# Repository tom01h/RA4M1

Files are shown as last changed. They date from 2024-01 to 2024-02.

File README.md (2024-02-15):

# Arduino UNO R4 もどき

## 買ったもの

- [これ(WeActStudio RA4M1)](https://ja.aliexpress.com/item/1005006103872563.html)の3.3V版
- 基板作った
    - LCDとI2C(J8)とUART(J7)とRTC電池(BT1)とSPIフラッシュ(U1)は使えた
    - 他にHX711とつなぐコネクタがある
    - Analog入力も後で試す

## Arduino化

- [Arduino公式のダウンロードページ](https://github.com/arduino/ArduinoCore-renesas/tree/main/bootloaders/UNO_R4)からファームウェア(dfu_minima.hex)をダウンロード
- [Renesas公式のダウンロードページ](https://www.renesas.com/us/en/software-tool/renesas-flash-programmer-programming-gui)からFlash Programmerをダウンロードしてインストール
    - ユーサー登録が必要だった
- [ここ](https://community.element14.com/products/arduino/b/blog/posts/arduino-uno-r4-minima-troubleshooting-unknown-usb-device)のReflash the Bootloader以降に従ってファームウェアを書き込む
    - USBでつなぐ
    - MDボタンを押しながらリセットを押してからはなす（そのあとでMDボタンをはなす）×2回？
        - UARTが生えてくるので番号を覚えておく
    - Flash Programmer起動
        - Connect Settings tabでUARTを選ぶ
        - dfu_minima.hexを読み込む
        - 新しいプロジェクトを作ってセーブ
        - Startを押す (書き込む)
- Example Blinkで確認
    - LED_BUILTINはこのボードにはついていない
    - LED_BUILTINをLED_TXに変更すると動いた（3か所）
- 他にも[サンプルがある](https://github.com/arduino/ArduinoCore-renesas/tree/main/libraries)

## OLED 表示
- SSD1306を使っている[128x32 OLED LCD](https://ja.aliexpress.com/item/32850288143.html)に表示する
- [ここ](https://101010.fun/iot/arduino-oled-display.html)を参考にした
- u8g2ライブラリをインストールする
- GND-＞GND:VCC-＞VCC:100->SCK:101->SDA につなぐ（J4につなぐ）
- OLED.ino を書き込む

## 温湿気圧・CO2濃度計
BME280とMH-Z19をつないで温度・湿度・気圧と二酸化炭素濃度を表示する  
5V電源がないので外部から持ってくる（GNDに注意！！）
- インストールするライブラリ
    - u8g2
    - SparkFun BME280
    - Mzh19 by Eduard
- ピン配は以下の図を参照
- weather.inoを書き込む

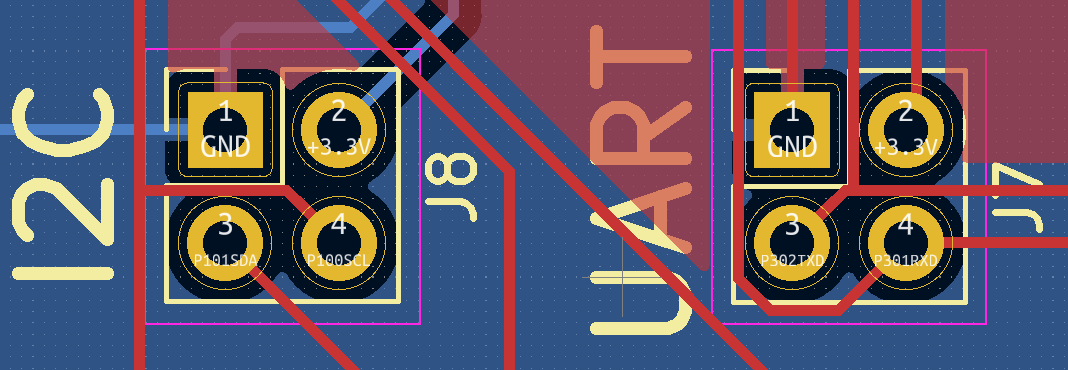
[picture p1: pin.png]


## 時計
RTC電池を使って時計を動かす（純正のR4 Minimaには電池繋げません）  
電池ホルターは[これ](https://ja.aliexpress.com/item/4000528748796.html)
- 電池ホルダーBT1にCR1220を入れる
- RTC_AutomaticExample.inoを書き込む
- [バッテリバックアップを使うとき](https://docs.arduino.cc/tutorials/uno-r4-wifi/vrtc-off/)を参考に改変している
- 内蔵クロックを使うと時計の精度がとっても悪いので[外部のオシレータを使う方法](https://me-yoh.com/arduino-uno-r4-rtc-fix)
    - VBATTを使うと外部のオシレータを発振出来ていません

## SPIフラッシュアクセス

[これ](https://ja.aliexpress.com/item/32326265518.html)
- ライブラリは[Arduino-W25Q64](https://github.com/Tamakichi/Arduino-W25Q64)
- READMEに従って手動でライブラリをインストール
- U1につなぐ
- 繋いでいるのはW25Q32だけど使えるらしい
- Arduino-W25Q64.inoを書き込む

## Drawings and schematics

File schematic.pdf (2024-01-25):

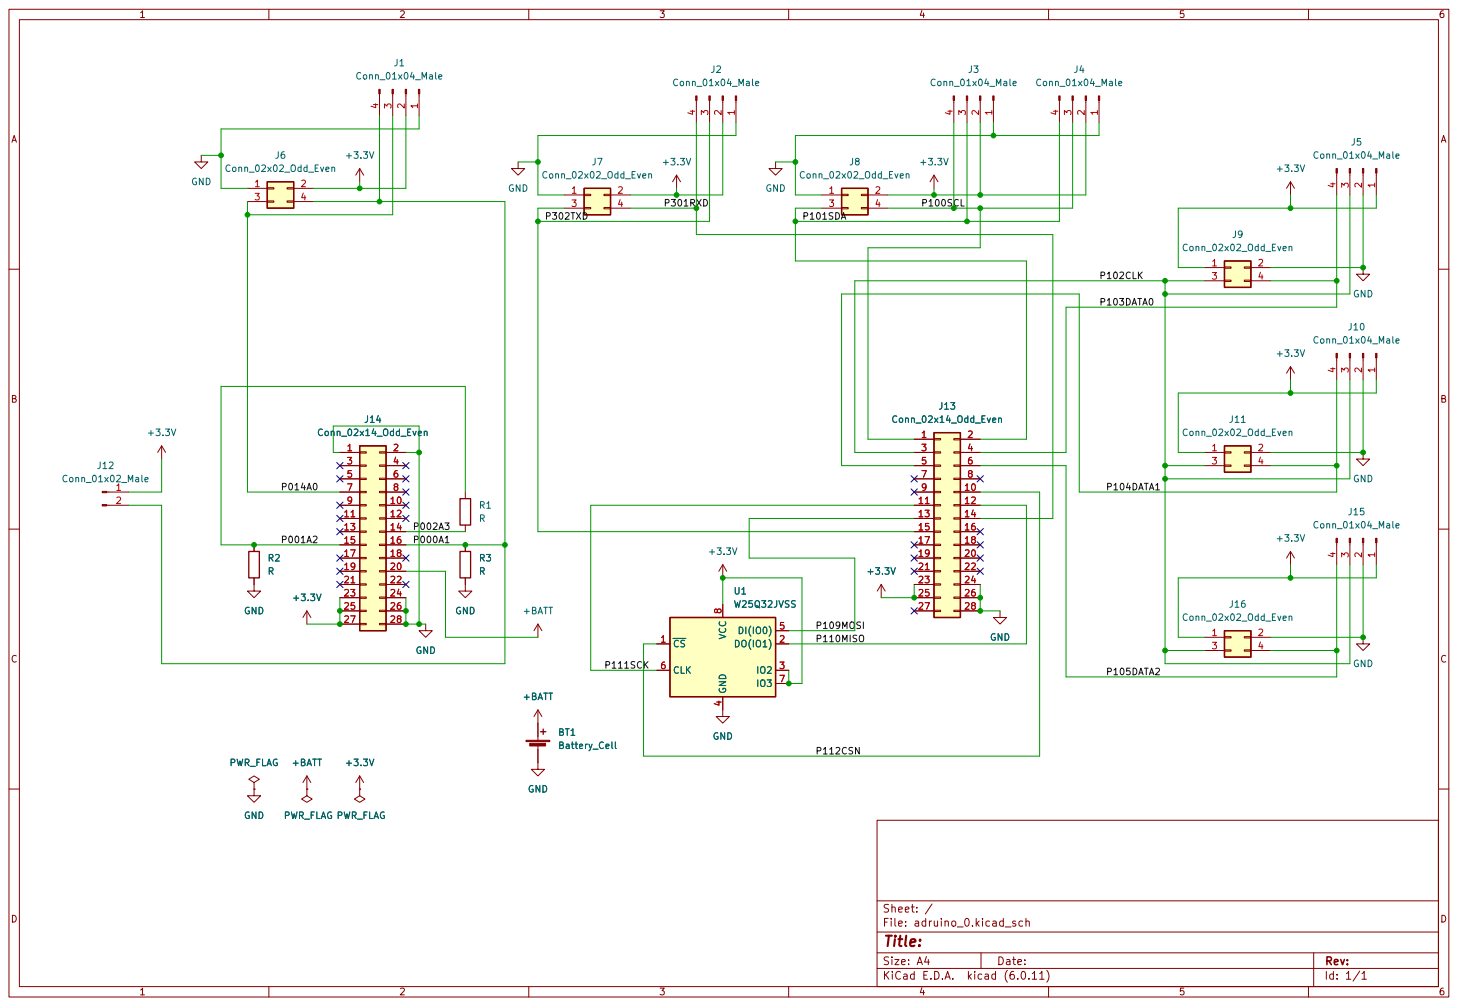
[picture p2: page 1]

Id: 1/1 Title: File: adruino_0.kicad_sch Sheet: /

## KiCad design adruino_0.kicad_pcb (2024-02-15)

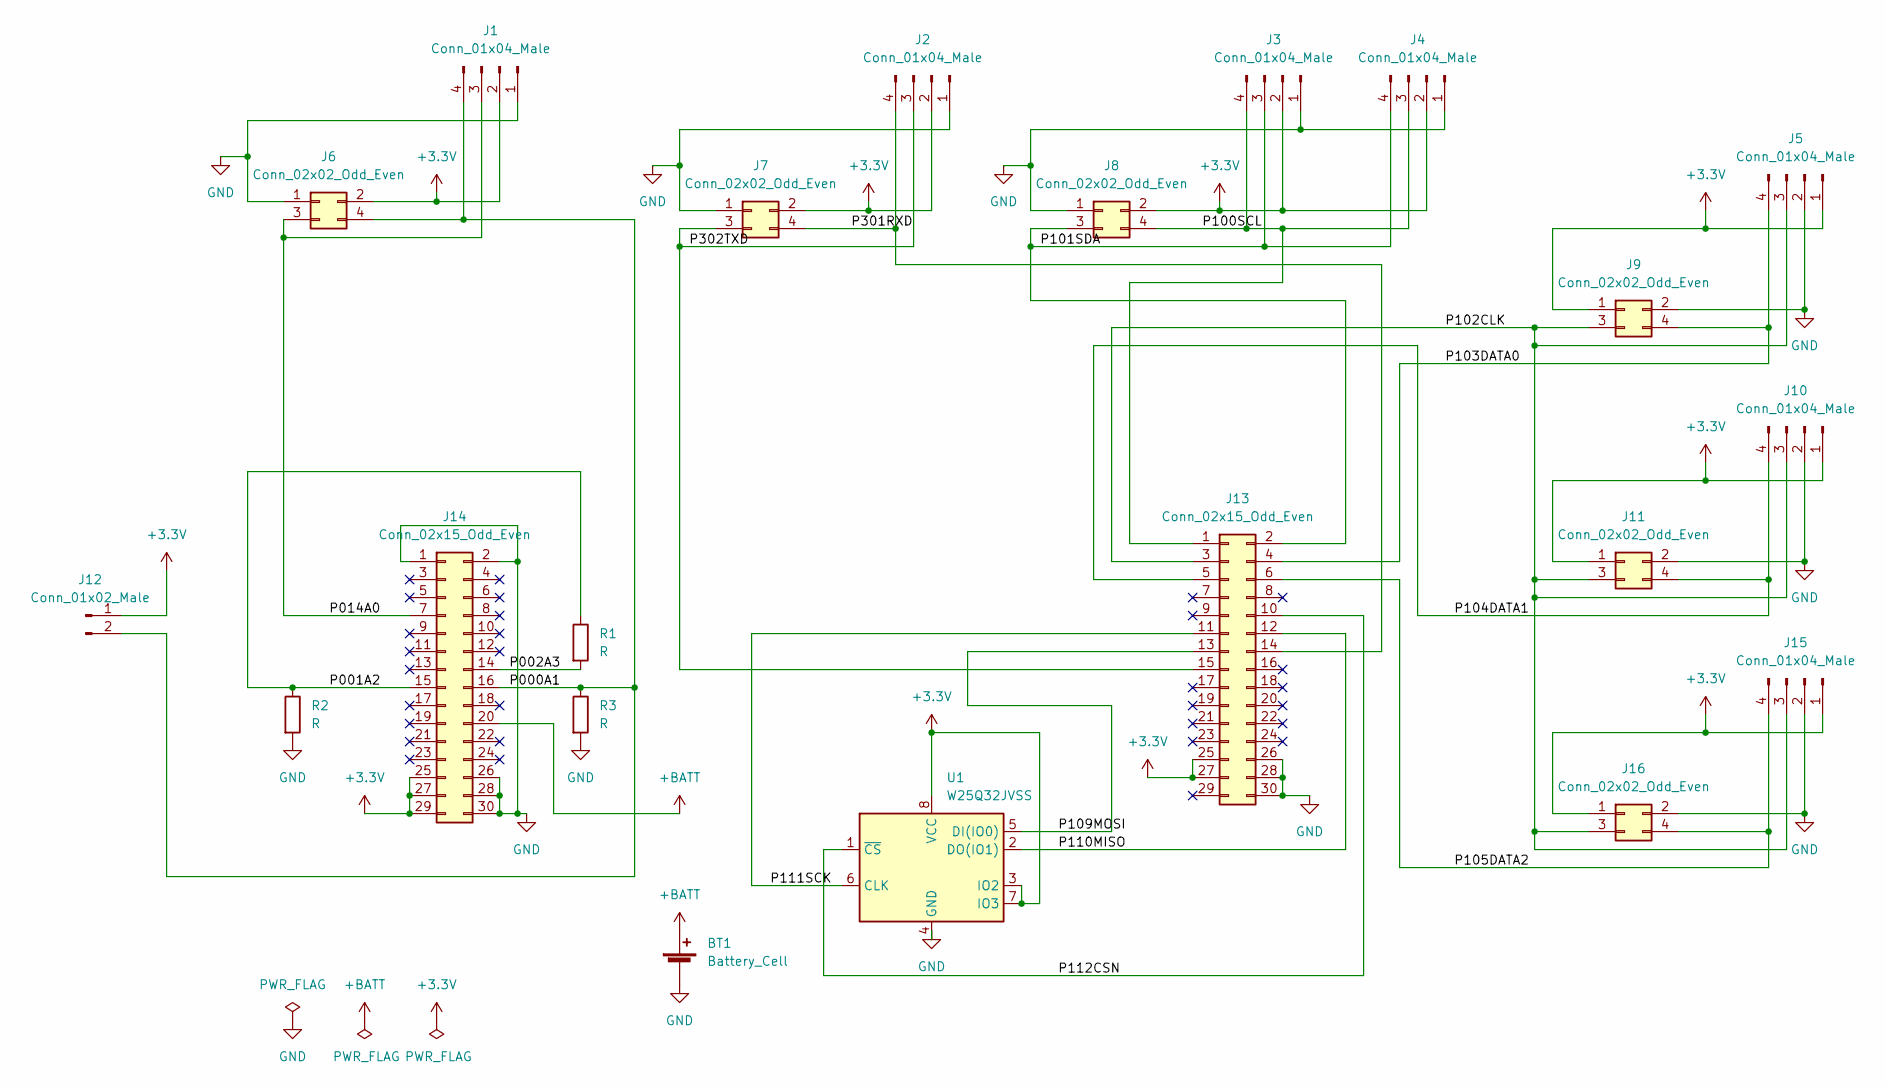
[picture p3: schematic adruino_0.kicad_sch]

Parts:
BT1: Battery_Cell; CH291-1220LF
J1, J2, J3, J5, J10, J15: Conn_01x04_Male; JST_PH_S4B-PH-K_1x04_P2.00mm_Horizontal
J4: Conn_01x04_Male; PinHeader_1x04_P2.54mm_Vertical
J6, J7, J8, J9, J11, J16: Conn_02x02_Odd_Even; PinHeader_2x02_P2.54mm_Vertical
J12: Conn_01x02_Male; PinHeader_1x02_P2.54mm_Vertical
J13, J14: Conn_02x15_Odd_Even; PinHeader_2x15_P2.54mm_Vertical
R1, R2, R3: R; R_1206_3216Metric_Pad1.30x1.75mm_HandSolder
U1: W25Q32JVSS; SOIC-8_5.23x5.23mm_P1.27mm

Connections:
+3.3V: J1.2, J2.2, J3.2, J4.2, J5.1, J6.2, J7.2, J8.2, J9.1, J10.1, J11.1, J12.1, J13.25, J13.27, J14.25, J14.27, J14.29, J15.1, J16.1, U1.3 (IO2), U1.7 (IO3), U1.8 (VCC)
+BATT: BT1.1 (+), J14.20
/P000A1: J1.4, J6.4, J12.2, J14.16, R3.1
/P001A2: J14.15, R1.1, R2.1
/P002A3: J14.14, R1.2
/P014A0: J1.3, J6.3, J14.7
/P100SCL: J3.4, J4.3, J8.4, J13.1
/P101SDA: J3.3, J4.4, J8.3, J13.2
/P102CLK: J5.3, J9.3, J10.3, J11.3, J13.3, J15.3, J16.3
/P103DATA0: J5.4, J9.4, J13.4
/P104DATA1: J10.4, J11.4, J13.5
/P105DATA2: J13.6, J15.4, J16.4
/P109MOSI: J13.13, U1.5 (DI(IO0))
/P110MISO: J13.12, U1.2 (DO(IO1))
/P111SCK: J13.11, U1.6 (CLK)
/P112CSN: J13.10, U1.1 (~CS)
/P301RXD: J2.4, J7.4, J13.14
/P302TXD: J2.3, J7.3, J13.15
GND: BT1.2 (-), J1.1, J2.1, J3.1, J4.1, J5.2, J6.1, J7.1, J8.1, J9.2, J10.2, J11.2, J13.26, J13.28, J13.30, J14.1, J14.2, J14.26, J14.28, J14.30, J15.2, J16.2, R2.2, R3.2, U1.4 (GND)

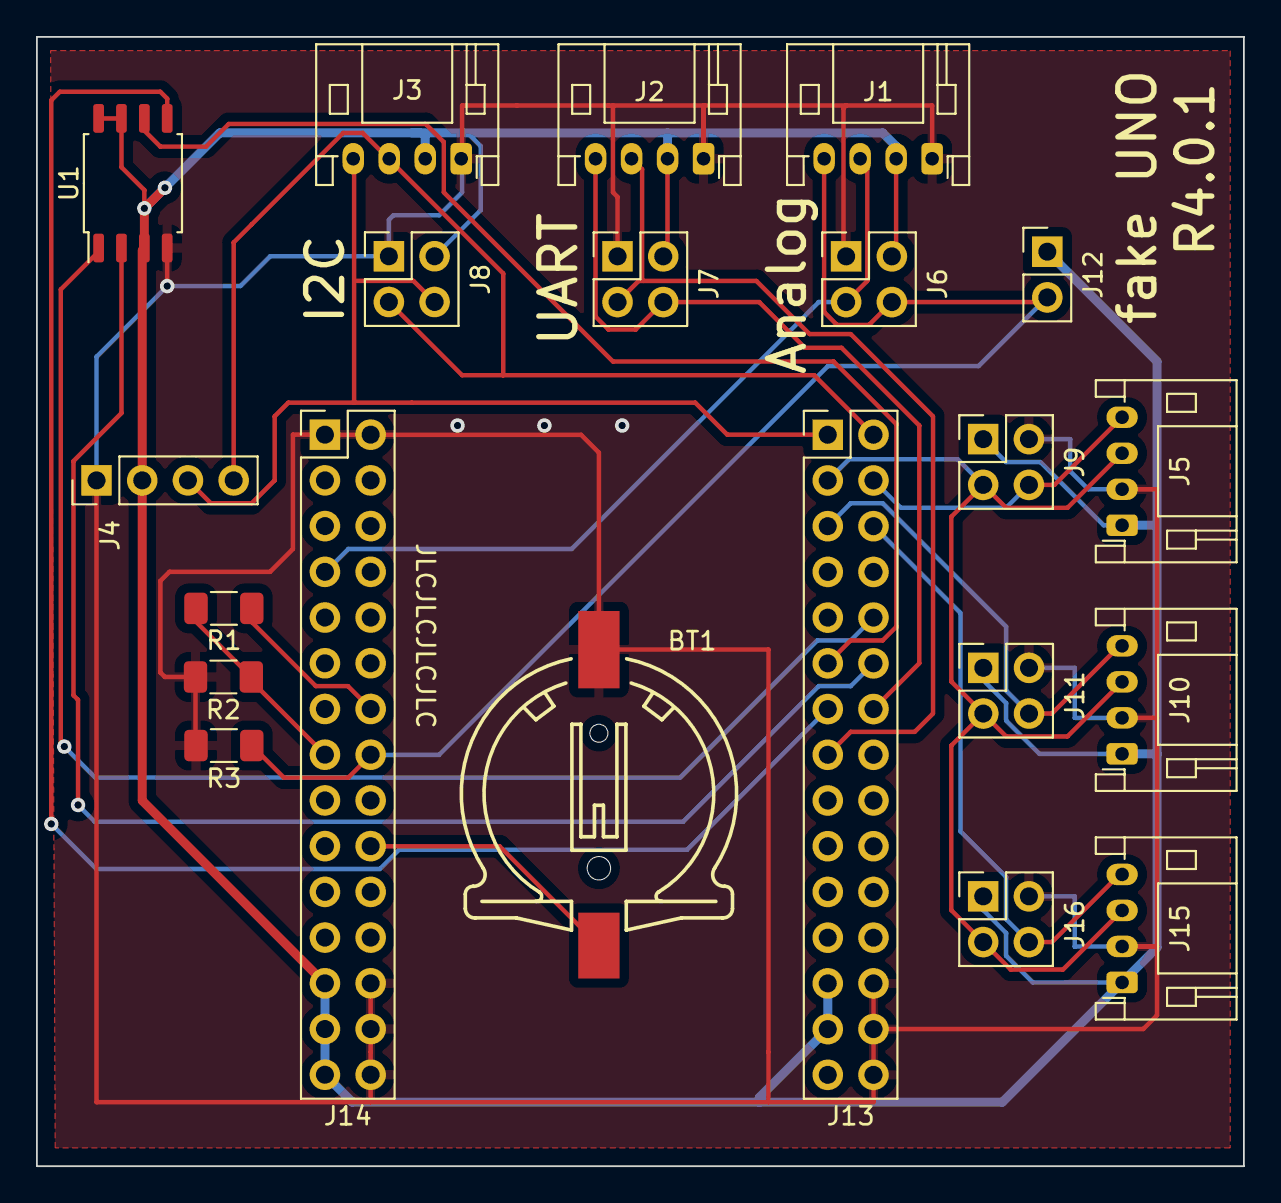
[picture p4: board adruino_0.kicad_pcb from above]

Board: 2 copper layers, 67.1 x 62.7 mm, 21 parts (0 on the bottom side), 19 nets.

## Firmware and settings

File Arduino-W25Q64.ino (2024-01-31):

//
// SPI シリアルフラッシュメモリ W25Q64 操作検証プログラム
// W25Q64のメモリ領域構造
//   総バイト数 8388608
//   メモリ空間 24ビットアドレス指定 0x00000 - 0x7FFFFF 
//   ブロック数 128 (64KB/ブロック)
//   セクタ数 2048  ( 4KB/セクタ)
//   総セクタ数 2048
//
//  修正 2020/05/12, Unique ID取得の修正
//

#include <string.h>
#include <W25Q64.h>

//
// 書込みデータのダンプリスト
// dt(in) : データ格納先頭アドレス
// n(in)  : 表示データ数
//
void dump(byte *dt, uint32_t n) {
  char buf[64];
  uint16_t clm = 0;
  byte data;
  byte sum;
  byte vsum[16];
  byte total =0;
  uint32_t saddr =0;
  uint32_t eaddr =n-1;
  
  Serial.println("----------------------------------------------------------");
  for (uint16_t i=0;i<16;i++) vsum[i]=0;  
  for (uint32_t addr = saddr; addr <= eaddr; addr++) {
    data = dt[addr];
    if (clm == 0) {
      sum =0;
      sprintf(buf,"%05lx: ",addr);
      Serial.print(buf);
    }

    sum+=data;
    vsum[addr % 16]+=data;
    
    sprintf(buf,"%02x ",data);
    Serial.print(buf);
    clm++;
    if (clm == 16) {
      sprintf(buf,"|%02x ",sum);
      Serial.print(buf);      
      Serial.println("");
      clm = 0;
    }    
  }
  Serial.println("----------------------------------------------------------");
  Serial.print("       ");
  for (uint16_t i=0; i<16;i++) {
    total+=vsum[i];
    sprintf(buf,"%02x ",vsum[i]);
    Serial.print(buf);
  }
  sprintf(buf,"|%02x ",total);
  Serial.print(buf);      
  Serial.println("");
  Serial.println("");
}

void setup() {
    byte buf[256];        // 取得データ
    byte wdata[16];       // 書込みデータ
    
    uint16_t n;           // 取得データ数
    
    W25Q64_begin(10);     // フラッシュメモリ利用開始
    Serial.begin(115200);
    while (!Serial) ;

    // JEDEC IDの取得テスト
    W25Q64_readManufacturer(buf);
    Serial.print("JEDEC ID : ");
    for (byte i=0; i< 3; i++) {
      Serial.print(buf[i],HEX);
      Serial.print(" ");
    }
    Serial.println("");
    
    // Unique IDの取得テスト
    memset(buf,0,8);
    W25Q64_readUniqieID(buf);
    Serial.print("Unique ID : ");
    for (byte i=0; i< 8; i++) {
      Serial.print(buf[i],HEX);
      Serial.print(" ");
    }
    Serial.println("");
    
    // データの読み込み(アドレス0から256バイト取得)
    memset(buf,0,256);
    n =  W25Q64_read(0,buf, 256);
    Serial.print("Read Data: n=");
    Serial.println(n,DEC);
    dump(buf,256);

    // 高速データの読み込み(アドレス0から256バイト取得)
    memset(buf,0,256);
    n =  W25Q64_fastread(0,buf, 256);
    Serial.print("Fast Read Data: n=");
    Serial.println(n,DEC);
    dump(buf,256);

    // セクタ単位の削除
    n = W25Q64_eraseSector(0,true);
    Serial.print("Erase Sector(0): n=");
    Serial.println(n,DEC);
    memset(buf,0,256);
    n =  W25Q64_read (0,buf, 256);
    dump(buf,256);
 
    // データ書き込みテスト
    for (byte i=0; i < 16;i++) {
      wdata[i]='A'+i;
    }  
    n =  W25Q64_pageWrite(0, 10, wdata, 16);
    Serial.print("page_write(0,10,d,16): n=");
    Serial.println(n,DEC);
    memset(buf,0,256);
    n =  W25Q64_read (0,buf, 256);
    dump(buf,256);

    // ステータスレジスタ1の取得
    buf[0] = W25Q64_readStatusReg1();
    Serial.print("Status Register-1: ");
    Serial.print(buf[0],BIN);
    Serial.println("");

    // ステータスレジスタ2の取得
    buf[0] = W25Q64_readStatusReg2();
    Serial.print("Status Register-2: ");
    Serial.print(buf[0],BIN);
    Serial.println("");
}

void loop() {

}

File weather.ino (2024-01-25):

#include <Wire.h>
#include "SparkFunBME280.h"

BME280 bme280;

#include <Mhz19.h>

Mhz19 mhz19;

#include <U8g2lib.h>

U8G2_SSD1306_128X32_UNIVISION_F_HW_I2C u8g2(U8G2_R2, /* reset=*/ U8X8_PIN_NONE);

void setup() {
  Serial.begin(115200);

  Wire.begin();
  bme280.setI2CAddress(0x76);
  if(bme280.beginI2C() == false) Serial.println("Sensor connect failed");

  Serial1.begin(9600);
  while(Serial1.available()){
    delay(2);
  }
  mhz19.begin(&Serial1);
  mhz19.setMeasuringRange(Mhz19MeasuringRange::Ppm_5000);
  mhz19.enableAutoBaseCalibration();
  
  u8g2.begin();

  u8g2.setFont(u8g2_font_6x10_tf);
  u8g2.drawStr(0,  7, "CO2 Sensor");
  u8g2.drawStr(0, 17, "Preheating...");
  u8g2.sendBuffer();

  while (!mhz19.isReady()) {
    delay(50);
  }
}

void loop() {
  float temp = bme280.readTempC();
  float hum = bme280.readFloatHumidity();
  float press = bme280.readFloatPressure() / 100.0;

  auto carbonDioxide = mhz19.getCarbonDioxide();
  
  char buf[30];
  char s[7];

  u8g2.clearBuffer();
  u8g2.setFont(u8g2_font_6x10_tf);

  dtostrf(temp, 5, 2, s);
  sprintf(buf, "%s C", s);
  u8g2.drawStr(0,  7, buf);

  dtostrf(hum, 5, 2, s);
  sprintf(buf, "%s %%", s);
  u8g2.drawStr(0, 17, buf);

  dtostrf(press, 6, 1, s);
  sprintf(buf, "%s hPa", s);
  u8g2.drawStr(0, 27, buf);

  u8g2.setFont(u8g2_font_crox4h_tf);
  sprintf(buf, "%4d ppm", (int)carbonDioxide);
  u8g2.drawStr(45, 15, buf);

  u8g2.sendBuffer();

  delay(5000);
}

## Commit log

2024-01-25 BME280 MZH19
    [adruino_0.kicad_pcb, adruino_0.kicad_sch]
2024-01-29 remove UART
2024-01-31 時計表示修正
2024-01-31 SPIフラッシュ
2024-02-15 基板更新
    [adruino_0.kicad_pcb, adruino_0.kicad_sch]
